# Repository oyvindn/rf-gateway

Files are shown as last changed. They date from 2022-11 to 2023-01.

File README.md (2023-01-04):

# rf-gateway

## Hardware

* [ESP32-WROOM-32D](https://www.espressif.com/sites/default/files/documentation/esp32-wroom-32d_esp32-wroom-32u_datasheet_en.pdf)
* [HopeRF RFM69CW 13DBM 868Mhz RF Transceiver Module](https://www.hoperf.com/modules/rf_transceiver/RFM69C.html)
* DS18B20 Digital temperature sensor

## Arduino sketch dependencies

* [Arduino core for the ESP32](https://github.com/espressif/arduino-esp32)
* [Arduino Client for MQTT](https://pubsubclient.knolleary.net/index.html)
* [RadioHead Packet Radio library for embedded microprocessors](http://www.airspayce.com/mikem/arduino/RadioHead/)

## Compile, upload and monitor ESP32 using the Arduino CLI

### Add secrets
Copy `arduino_secrets.h.example` to `arduino_secrets.h` and change the example secret values.

### Download and install Arduino IDE and/or CLI
[Arduino CLI](https://arduino.github.io/arduino-cli/) is an all-in-one solution that provides Boards/Library Managers, sketch builder, board detection, uploader, and many other tools needed to use any Arduino compatible board and platform from command line or machine interfaces.

### Initialiazies a Arduino CLI new configuration:
`arduino-cli config init`

### Add URL for Arduino core for the ESP32, ESP32-S2 and ESP32-C3
Edit `~/Library/Arduino15/arduino-cli.yaml` and add:

```
board_manager:
  additional_urls:
  - https://raw.githubusercontent.com/espressif/arduino-esp32/gh-pages/package_esp32_index.json
```

### Update the core list
`arduino-cli core update-index`

### Install Arduino core for the ESP32, ESP32-S2 and ESP32-C3
`arduino-cli core install esp32:esp32`

### Compile sketch
`arduino-cli compile -b esp32:esp32:esp32 rf-gateway.ino`

### Upload sketch to ESP32:
`arduino-cli upload -p /dev/cu.usbserial-A600K4HV -b esp32:esp32:esp32 rf-gateway.ino`

### Open the serial monitor
`arduino-cli monitor -p /dev/cu.usbserial-A600K4HV -c baudrate=115200`

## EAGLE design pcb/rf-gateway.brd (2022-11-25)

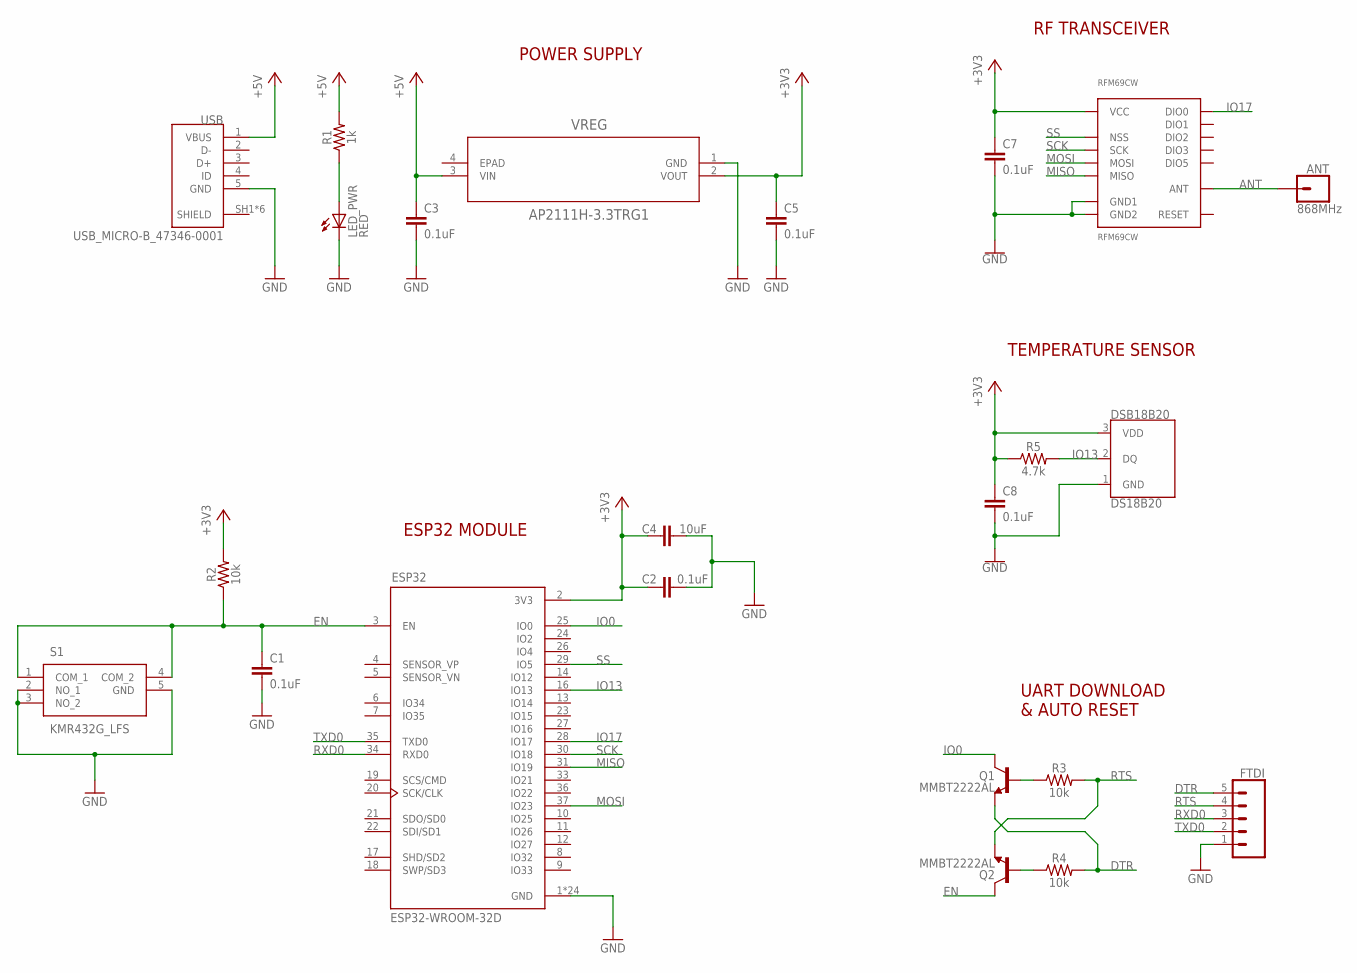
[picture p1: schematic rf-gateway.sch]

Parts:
ANT: 868MHz; 1X01
C1, C2, C3, C5, C7, C8: 0.1uF; 0603
C4: 10uF; 0805
DSB18B20: DS18B20; TO-92-AMMO
ESP32: ESP32-WROOM-32D
FTDI: CONN_05; 1X05
LED_PWR: RED; CHIPLED_0805
Q1, Q2: MMBT2222AL; SOT23-3
R1: 1k; 0603
R2, R3, R4: 10k; 0603
R5: 4.7k; 0603
RFM69CW: RFM69CW
S1: KMR432G_LFS; KMR421GULCLFS
USB: USB_MICRO-B_47346-0001; MOLEX_47346-0001
VREG: AP2111H-3.3TRG1; SOT-223_DIO

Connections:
+3V3: C2.1, C4.1, C5.1, C7.1, C8.1, DSB18B20.3 (VDD), ESP32.2 (3V3), R2.2, R5.1, RFM69CW.VDD (VCC), VREG.2 (VOUT)
+5V: C3.1, R1.2, USB.1 (VBUS), VREG.3 (VIN)
ANT: ANT.1, RFM69CW.ANT
DTR: FTDI.5, Q1.2 (E), R4.2
EN: C1.1, ESP32.3 (EN), Q2.3 (C), R2.1, S1.1 (COM_1), S1.4 (COM_2)
GND: C1.2, C2.2, C3.2, C4.2, C5.2, C7.2, C8.2, DSB18B20.1 (GND), ESP32.1 (GND), ESP32.15 (GND), ESP32.38 (GND), ESP32.39_1 (GND), ESP32.39_2 (GND), ESP32.39_3 (GND), ESP32.39_4 (GND), ESP32.39_5 (GND), ESP32.39_6 (GND), ESP32.39_7 (GND), ESP32.39_8 (GND), ESP32.39_9 (GND), ESP32.39_10 (GND), ESP32.39_11 (GND), ESP32.39_12 (GND), ESP32.39_13 (GND), ESP32.39_14 (GND), ESP32.39_15 (GND), ESP32.39_16 (GND), ESP32.39_17 (GND), ESP32.39_18 (GND), ESP32.39_19 (GND), ESP32.39_20 (GND), ESP32.39_21 (GND), FTDI.1, LED_PWR.C, RFM69CW.GND@1 (GND1), RFM69CW.GND@2 (GND2), S1.2 (NO_1), S1.3 (NO_2), S1.5 (GND), USB.5 (GND), VREG.1 (GND)
IO0: ESP32.25 (IO0), Q1.3 (C)
IO13: DSB18B20.2 (DQ), ESP32.16 (IO13), R5.2
IO17: ESP32.28 (IO17), RFM69CW.DIO0
MISO: ESP32.31 (IO19), RFM69CW.MISO
MOSI: ESP32.37 (IO23), RFM69CW.MOSI
unnamed: LED_PWR.A, R1.1
unnamed: Q1.1 (B), R3.1
unnamed: Q2.1 (B), R4.1
RTS: FTDI.4, Q2.2 (E), R3.2
RXD0: ESP32.34 (RXD0), FTDI.3
SCK: ESP32.30 (IO18), RFM69CW.SCK
SS: ESP32.29 (IO5), RFM69CW.NSS
TXD0: ESP32.35 (TXD0), FTDI.2

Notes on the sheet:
ESP32 MODULE
UART DOWNLOAD & AUTO RESET
POWER SUPPLY
RF TRANSCEIVER
TEMPERATURE SENSOR

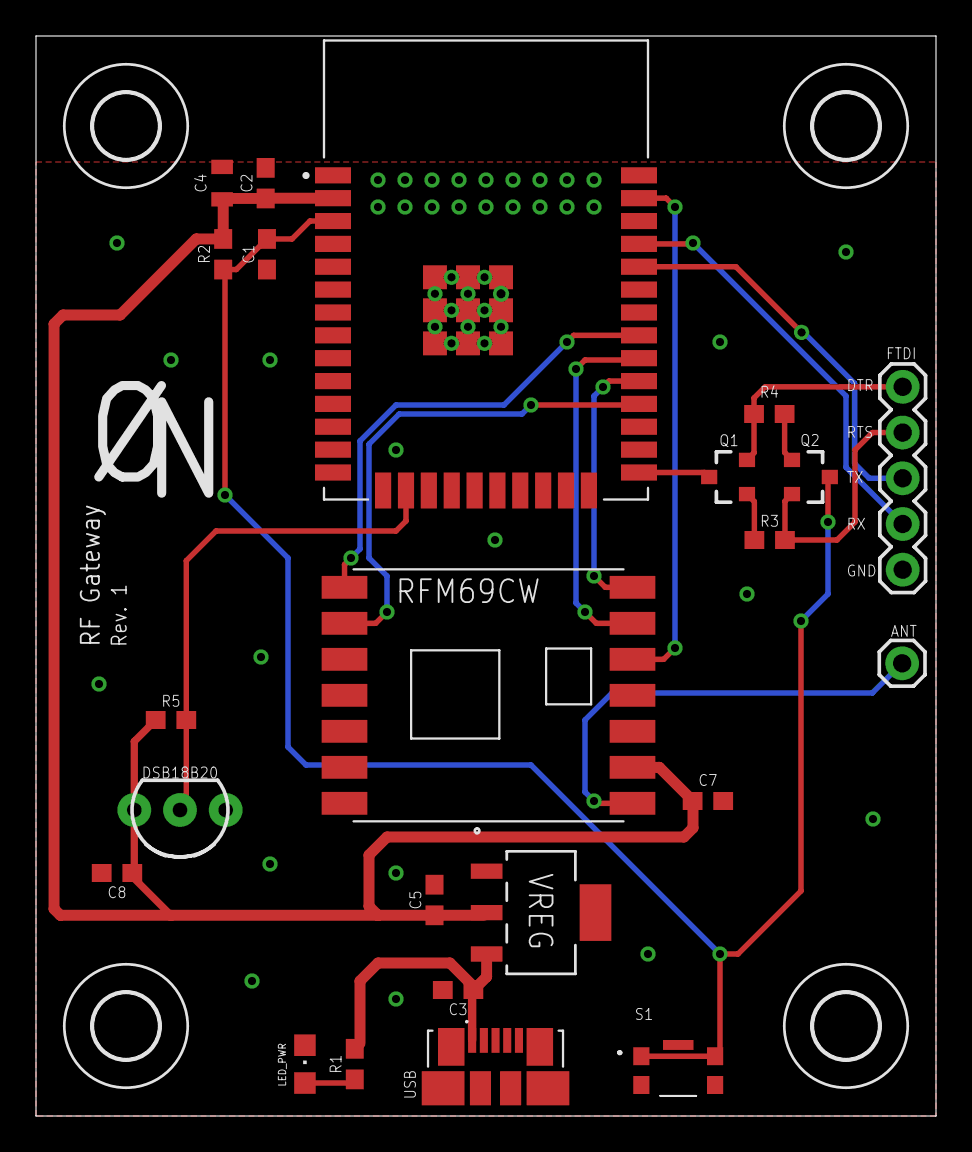
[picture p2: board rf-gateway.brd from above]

Board: 2 copper layers, 50.0 x 60.0 mm, 27 parts (0 on the bottom side), 19 nets.

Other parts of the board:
U$1, U$2, U$3, U$4: 3,6

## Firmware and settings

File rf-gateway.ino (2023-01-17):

#include <SPI.h>
#include <RH_RF69.h>
#include <RHReliableDatagram.h>
#include <ESPmDNS.h>
#include <WiFiUdp.h>
#include <ArduinoOTA.h>
#include <WiFiClientSecure.h>
#include <PubSubClient.h>
#include <OneWire.h>
#include <DallasTemperature.h>

#include "arduino_secrets.h"

#define WIFI_RECOVER_TIME_MS 10000 // Wait time after a failed connection attempt

#define OTA_HOSTNAME "rf-gateway-esp32"

#define MQTT_BROKER_PORT 8883
#define MQTT_CLIENT_ID "rf-gateway"
#define MQTT_RECOVER_TIME_MS 10000 // Wait time after a failed connection attempt
#define RF_GATEWAY_TOPIC "home/rf-gateway"

#define RF_INTERRUPT_GPIO 17
#define RF_FREQUENCY 868.00
#define RF_GATEWAY_ADDRESS 1

#define DS18B20_TEMPERATURE_SENSOR_PIN 13
#define DS18B20_TEMPERATURE_POLL_INTERVALL_MS 60000

RH_RF69 rf69Driver(SS, RF_INTERRUPT_GPIO);
RHReliableDatagram radioManager(rf69Driver, RF_GATEWAY_ADDRESS);

WiFiClientSecure wifiClientSecure;
PubSubClient mqttClient(MQTT_BROKER_HOST, MQTT_BROKER_PORT, wifiClientSecure);

OneWire oneWire(DS18B20_TEMPERATURE_SENSOR_PIN);
DallasTemperature temperatureSensors(&oneWire);

uint8_t rfReceiveBuffer[RH_RF69_MAX_MESSAGE_LEN];
char rfMessageBuffer[80];
char *rfMessageReadyToBeSent = NULL;
char tempMessageBuffer[80];
char *tempMessageReadyToBeSent = NULL;

unsigned long lastMqttReconnectAttempt = 0;
unsigned long lastTemperatureReading = 0;

void setup()
{
  Serial.begin(115200);
  while (!Serial)
    ;

  ensureWifiConnection();
  initRadio();
  initMQTT();
  initOTA();
  temperatureSensors.begin();
}

void loop()
{
  ensureWifiConnection();
  rfReceive();
  readDS18B20Temperature();
  sendQueuedMessagesToMqtt();
  ArduinoOTA.handle();
}

void ensureWifiConnection()
{
  if (WiFi.status() != WL_CONNECTED)
  {
    Serial.println("[WIFI] Connecting");
    WiFi.enableSTA(true);
    WiFi.begin(WIFI_SSID, WIFI_PASSWORD);

    if (WiFi.waitForConnectResult() == WL_CONNECTED)
    {
      Serial.println("[WIFI] Connected");
      Serial.print("[WIFI] IP address: ");
      Serial.println(WiFi.localIP());
    }
    else
    {
      Serial.println("[WIFI] Failed");
      delay(WIFI_RECOVER_TIME_MS);
      ESP.restart();
    }
  }
}

void initRadio()
{
  if (radioManager.init())
  {
    Serial.println("[RFM69] Init success");
  }
  else
  {
    Serial.println("[RFM69] Init failed");
  }
  // Defaults after init are 434.0MHz, modulation GFSK_Rb250Fd250, +13dbM (for low power module)
  if (rf69Driver.setFrequency(RF_FREQUENCY))
  {
    Serial.print("[RFM69] Frequency set to ");
    Serial.print(RF_FREQUENCY);
    Serial.println("MHz");
  }
  else
  {
    Serial.println("[RFM69] Failed to set frequency");
  }

  uint8_t encryptionKey[] = SECRET_RF_ENCRYPTION_KEY;
  rf69Driver.setEncryptionKey(encryptionKey);
}

void initMQTT()
{
  wifiClientSecure.setCACert(root_ca_certificate);
  wifiClientSecure.setCertificate(client_certificate);
  wifiClientSecure.setPrivateKey(client_private_key);

  mqttClient.setSocketTimeout(10);
}

void initOTA()
{
  ArduinoOTA.setHostname(OTA_HOSTNAME);
  ArduinoOTA.setPasswordHash(OTA_PASSWORD_MD5_HASH);

  ArduinoOTA.onStart([]()
                     {
    String type;
    if (ArduinoOTA.getCommand() == U_FLASH)
    {
        type = "sketch";
    }
    else
    {
        type = "filesystem";
    }
    Serial.println("[OTA] Start updating " + type); })
      .onEnd([]()
             { Serial.println("\n[OTA] End"); })
      .onProgress([](unsigned int progress, unsigned int total)
                  { Serial.printf("[OTA] Progress: %u%%\r", (progress / (total / 100))); })
      .onError([](ota_error_t error)
               {
      Serial.printf("[OTA] Error[%u]: ", error);
      if (error == OTA_AUTH_ERROR)
          Serial.println("Auth Failed");
      else if (error == OTA_BEGIN_ERROR)
          Serial.println("Begin Failed");
      else if (error == OTA_CONNECT_ERROR)
          Serial.println("Connect Failed");
      else if (error == OTA_RECEIVE_ERROR)
          Serial.println("Receive Failed");
      else if (error == OTA_END_ERROR)
          Serial.println("End Failed"); });

  ArduinoOTA.begin();
}

void rfReceive()
{
  if (radioManager.available())
  {
    uint8_t len = sizeof(rfReceiveBuffer);
    uint8_t from;
    if (radioManager.recvfromAck(rfReceiveBuffer, &len, &from))
    {
      Serial.print("[RFM69] Message received from node ");
      Serial.print(from);
      Serial.print(": ");
      Serial.println((char *)rfReceiveBuffer);

      sprintf(rfMessageBuffer, "%d;%s", from, rfReceiveBuffer);
      rfMessageReadyToBeSent = rfMessageBuffer;
    }
  }
}

void sendQueuedMessagesToMqtt()
{
  if (!mqttClient.connected())
  {
    tryConnectToMqtt();
  }
  else
  {
    if (rfMessageReadyToBeSent != NULL && sendMessageToMqtt(RF_GATEWAY_TOPIC, rfMessageReadyToBeSent))
    {
      rfMessageReadyToBeSent = NULL;
    }

    if (tempMessageReadyToBeSent != NULL && sendMessageToMqtt(RF_GATEWAY_TOPIC, tempMessageReadyToBeSent))
    {
      tempMessageReadyToBeSent = NULL;
    }

    mqttClient.loop();
  }
}

void tryConnectToMqtt()
{
  if (lastMqttReconnectAttempt == 0 || millis() - lastMqttReconnectAttempt >= MQTT_RECOVER_TIME_MS)
  {
    lastMqttReconnectAttempt = millis();

    Serial.println("[MQTT] Connecting");

    if (mqttClient.connect(MQTT_CLIENT_ID))
    {
      lastMqttReconnectAttempt = 0;
      Serial.println("[MQTT] Connected to broker");
    }
    else
    {
      Serial.print("[MQTT] Connection failed, rc=");
      Serial.println(mqttClient.state());
    }
  }
}

bool sendMessageToMqtt(const char *topic, const char *message)
{
  Serial.print("[MQTT] Sending message \"");
  Serial.print(message);
  Serial.print("\" on topic \"");
  Serial.print(topic);
  Serial.println("\"");

  boolean publishSucceeded = mqttClient.publish(topic, message, false);
  if (publishSucceeded)
  {
    Serial.println("[MQTT] Message sent");
    return true;
  }
  else
  {
    Serial.println("[MQTT] Sending failed");
    return false;
  }
}

void readDS18B20Temperature()
{
  if (lastTemperatureReading == 0 || millis() - lastTemperatureReading >= DS18B20_TEMPERATURE_POLL_INTERVALL_MS)
  {
    lastTemperatureReading = millis();

    temperatureSensors.requestTemperatures();
    float temp = temperatureSensors.getTempCByIndex(0);
    char temperatureStr[10];
    dtostrf(temp, 1, 2, temperatureStr);

    Serial.print("[DS18B20] Temperature is \"");
    Serial.print(temperatureStr);
    Serial.println("\"");

    sprintf(tempMessageBuffer, "1;T;%s", temperatureStr);
    tempMessageReadyToBeSent = tempMessageBuffer;
  }
}

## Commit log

2022-03-17 Change port to match the ESP32-DevKitC
2022-03-26 Changed from DevKitC to Adafruit HUZZAH32 - ESP32 Feather
2022-06-28 Print actual radio frequency
2022-11-25 Add PCB design rev. 1
    [rf-gateway.brd, rf-gateway.sch]
2023-01-04 Switch to homemade PCB design
2023-01-17 Add temperature reading inside the enclosure

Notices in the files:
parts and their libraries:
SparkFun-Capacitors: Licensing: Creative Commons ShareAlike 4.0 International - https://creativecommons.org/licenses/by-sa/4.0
